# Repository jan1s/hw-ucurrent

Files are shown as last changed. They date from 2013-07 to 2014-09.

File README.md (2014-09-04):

# uCurrent Clone

This is a copy of the famous µCurrent of Dave Jones from EEVBlog.
Have a look at the [original project site](http://www.eevblog.com/projects/ucurrent/).

## Hardware

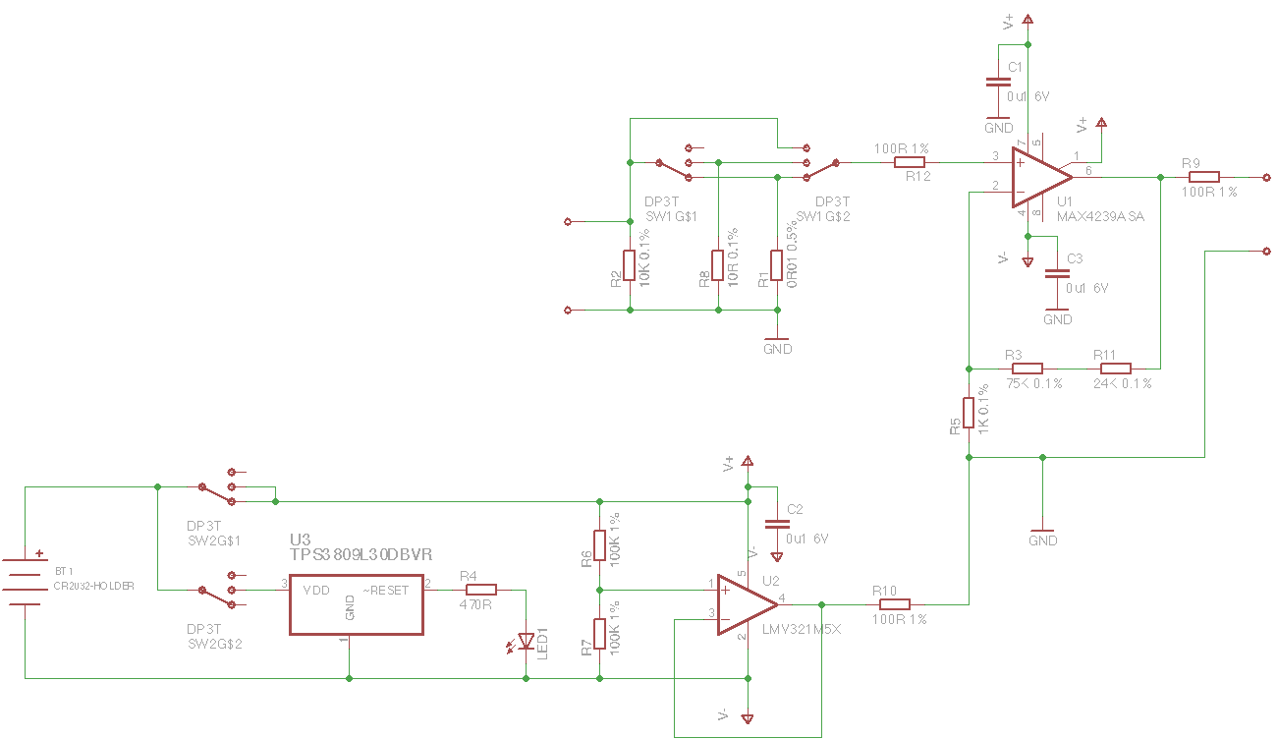
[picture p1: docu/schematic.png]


Project schematic.

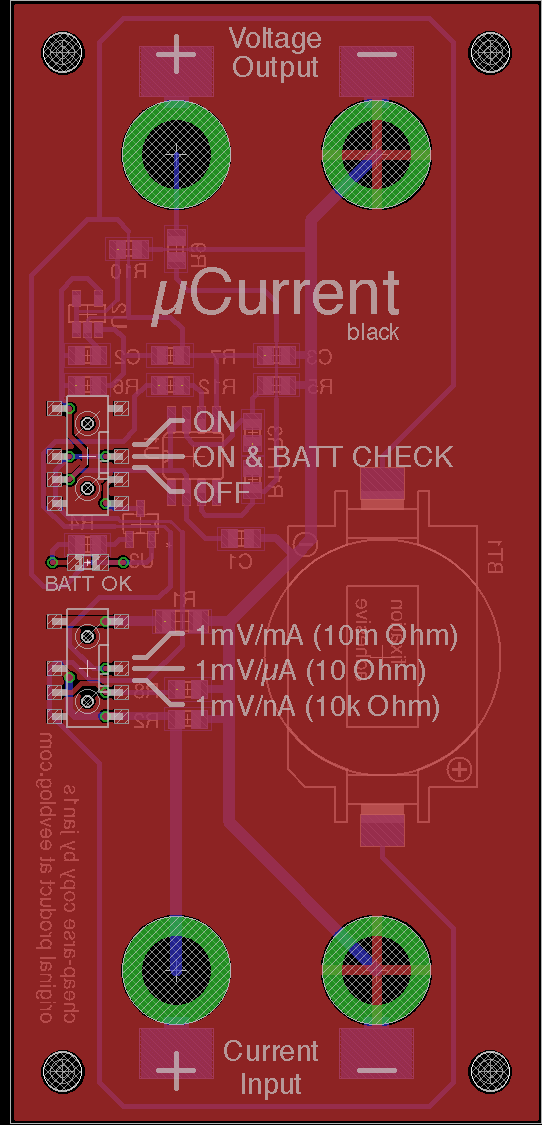
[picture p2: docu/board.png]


Project board render.

## BOM
| Identifier | Type/Value | Quantity | Supplier Id | Supplier | Comment |
| --- | --- | --- | --- | --- | --- |
| R1 | 0.01 Ω 0.5% | 1 | 603-RL1206FR070R01L | [Mouser][mouser] |
| R8 | 10 Ω 0.1% | 1 | 279-RP73D2A10RBTG | [Mouser][mouser] |
| R9, R10, R12 | 100 Ω 1% | 3 | SMD-0603 100 | [Reichelt][reichelt] |
| R4 | 470 Ω | 1 | SMD-0603 470 | [Reichelt][reichelt] |
| R5 | 1 kΩ 0.1% | 1 | SPR-0603 1,00K | [Reichelt][reichelt] |
| R2 | 10 kΩ 0.1% | 1 | SPR-0603 10,0K | [Reichelt][reichelt] |
| R11 | 24 kΩ 0.1% | 1 | SPR-0603 24,0K | [Reichelt][reichelt] |
| R3 | 75 kΩ 0.1% | 1 | SPR-0603 75,0K | [Reichelt][reichelt] |
| R6, R7 | 100 kΩ 1% | 2 | SMD-0603 100K | [Reichelt][reichelt] |
| C3, C8, C13, C14 | 100 nF | 4 | X7R-G0603 100N | [Reichelt][reichelt] |
| LED1 | LED green | 1 | LG L29K | [Reichelt][reichelt] |
| J1 | Banana Jack | 1 | PK 4 SW | [Reichelt][reichelt] |
| J2 | Banana Jack | 1 | PK 4 RT | [Reichelt][reichelt] |
| J3 | Banana Jack | 1 | BB 4 SW | [Reichelt][reichelt] |
| J4 | Banana Jack | 1 | BB 4 RT | [Reichelt][reichelt] |
| BAT | Batteryholder | 1 | KZH 20SMD-2 | [Mouser][mouser] |
| SW1, SW2 | Switch | 2 | Switches Micro SMD | [Aliexpress][aliexpress] |
| U1 | MAX4239ASA | 1 | 700-MAX4239ASA | [Mouser][mouser] |
| U2 | LMV321M5X | 1 | 926-LMV321M5X/NOPB | [Mouser][mouser] |
| U3 | TPS3809L30DBVR | 1 | 595-TPS3809L30DBVTG4 | [Mouser][mouser] |

[reichelt]: http://www.reichelt.de
[mouser]: http://mouser.com
[aliexpress]: http://www.aliexpress.com

## license



This work is licensed under a [Creative Commons Attribution-ShareAlike 3.0 Unported License](http://creativecommons.org/licenses/by-sa/3.0/).

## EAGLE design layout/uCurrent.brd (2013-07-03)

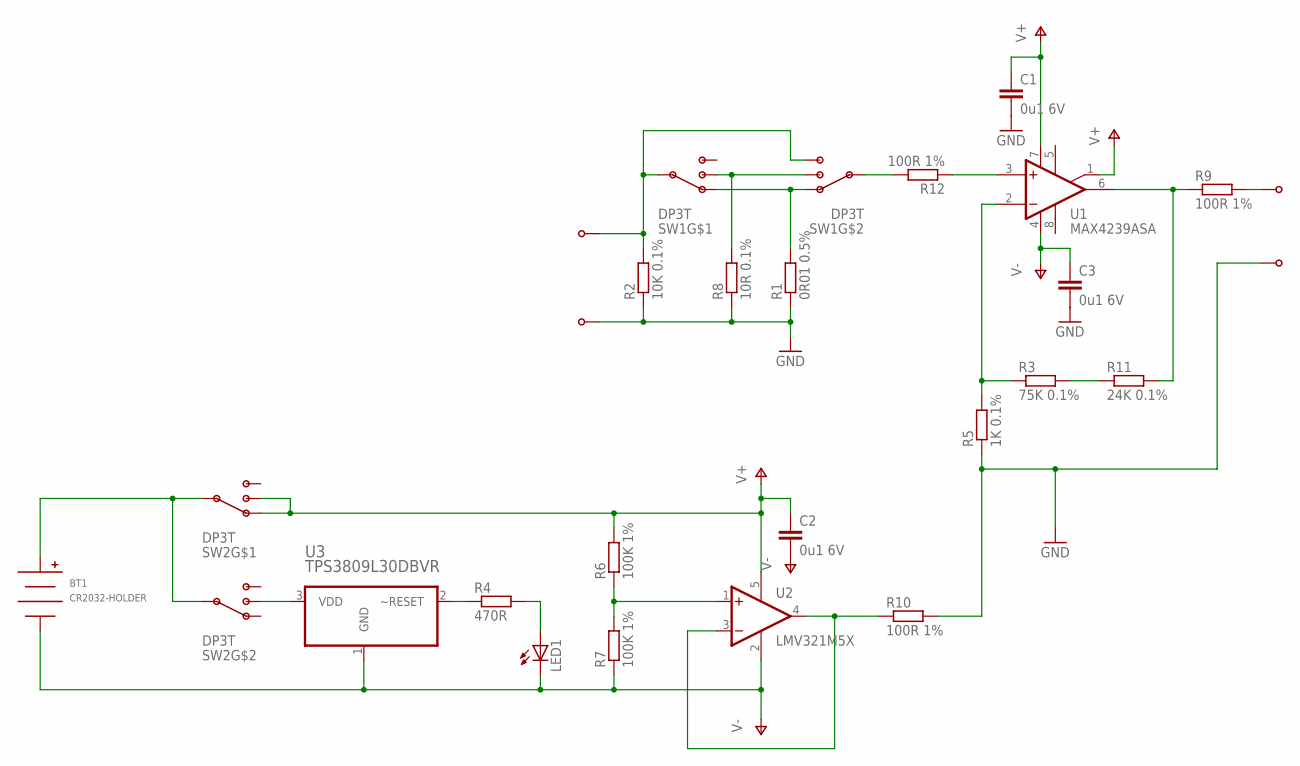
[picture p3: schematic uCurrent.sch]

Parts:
BT1: CR2032-HOLDER; CH28-2032LF
C1, C2, C3: 0u1 6V; C0805
LED1: LEDCHIPLED_0805; CHIPLED_0805
R1: 0R01 0.5%; R1206
R2: 10K 0.1%; R0805
R3: 75K 0.1%; R0805
R4: 470R; R0805
R5: 1K 0.1%; R0805
R6, R7: 100K 1%; R0805
R8: 10R 0.1%; R0805
R9, R10, R12: 100R 1%; R0805
R11: 24K 0.1%; R0805
SW1, SW2: DP3T
U1: MAX4239ASA; SO08
U2: LMV321M5X; SOT23-5
U3: TPS3809L30DBVR; SOT95P280X145-3N
U$2, U$3, U$4, U$5: BANANA-JACK; BANANA-PRINT

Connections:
GND: C1.2, C3.2, R1.1, R2.1, R5.1, R8.1, R10.2, U$3.P$1, U$5.P$1
unnamed: R10.1, U2.3 (-IN), U2.4 (OUT)
unnamed: R2.2, SW1.P$4 (1), SW1.P$C1 (C), U$2.P$1
unnamed: R8.2, SW1.P$2 (2), SW1.P$5 (2)
unnamed: R1.2, SW1.P$3 (3), SW1.P$6 (3)
unnamed: R3.2, R11.1
unnamed: R3.1, R5.2, U1.2 (-IN)
unnamed: R12.2, SW1.P$C2 (C)
unnamed: R9.1, R11.2, U1.6 (OUT)
unnamed: R12.1, U1.3 (+IN)
unnamed: R6.1, R7.2, U2.1 (+IN)
unnamed: R4.1, U3.2 (~RESET)
unnamed: LED1.A, R4.2
unnamed: SW2.P$5 (2), U3.3 (VDD)
unnamed: BT1.POS, SW2.P$C1 (C), SW2.P$C2 (C)
unnamed: R9.2, U$4.P$1
V+: C1.1, C2.1, R6.2, SW2.P$2 (2), SW2.P$3 (3), U1.1 (NC), U1.7 (V+), U2.5 (V+)
V-: BT1.NEG, C2.2, C3.1, LED1.C, R7.1, U1.4 (V-), U2.2 (V-), U3.1 (GND)

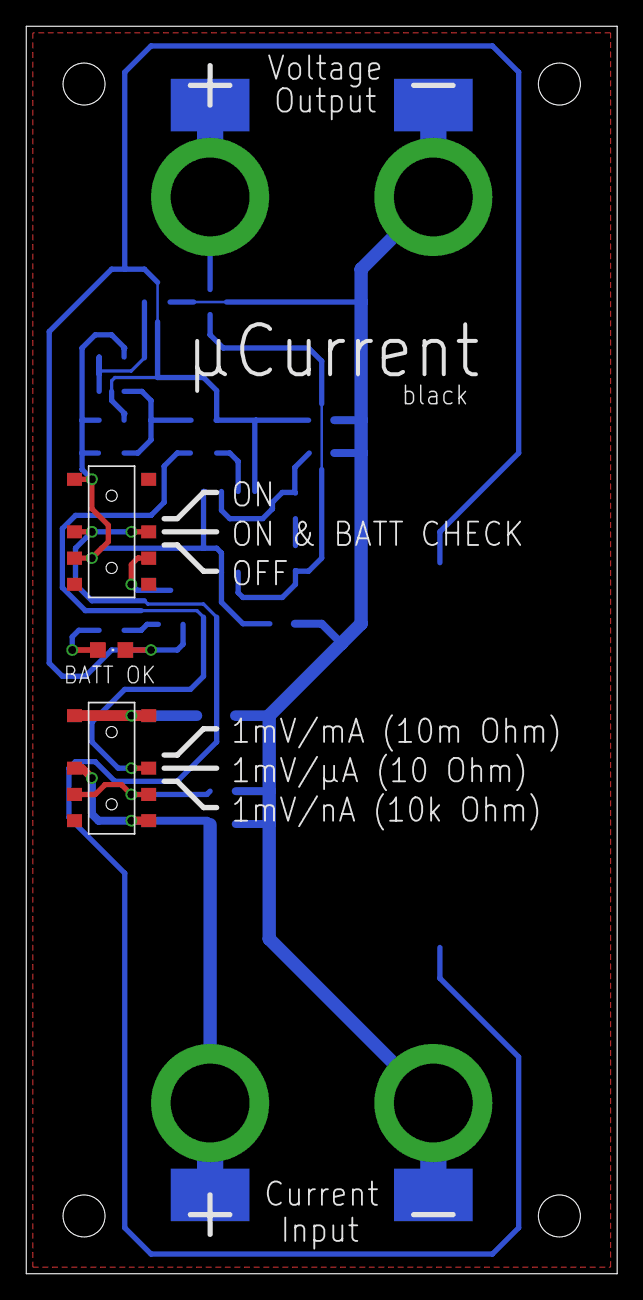
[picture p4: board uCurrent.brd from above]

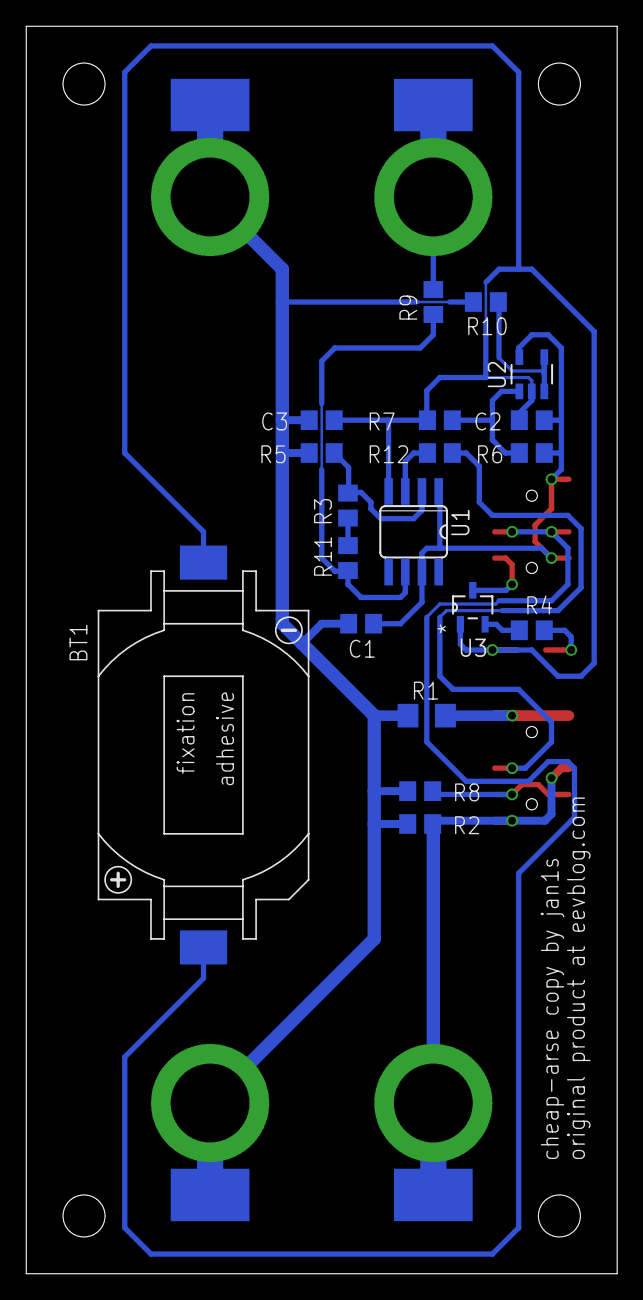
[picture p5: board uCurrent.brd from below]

Board: 2 copper layers, 45.0 x 95.0 mm, 26 parts (23 on the bottom side), 18 nets.

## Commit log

2013-06-29 Forgot first Pin on OpAmp
    [uCurrent.brd, uCurrent.sch]
2013-07-03 Fixed solderstop on banana jack
    [uCurrent.brd, uCurrent.sch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]
2014-04-15 Updated Readme with BOM
2014-04-15 Added Banana Plugs to BOM
